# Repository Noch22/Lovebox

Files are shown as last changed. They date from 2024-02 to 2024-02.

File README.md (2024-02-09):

# Lovebox DIY :love_letter:

Envie d'envoyer de l'amour à ton partenaire, où simplement quelqu'un que tu aime ? Tu as envie de créer ? Ce projet est fait pour toi !

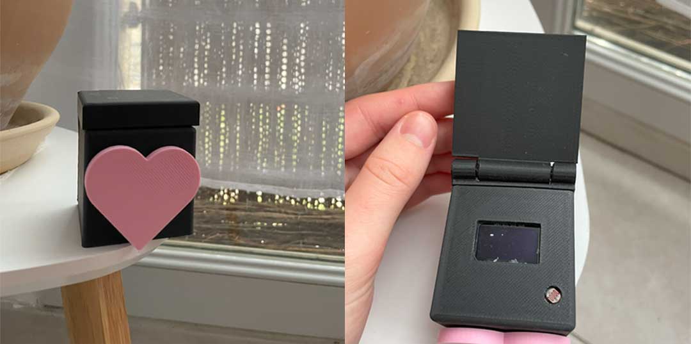
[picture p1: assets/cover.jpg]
Photo de la lovebox

## :shopping_cart: Liste des courses 
 - Wemos D1 Mini
   - [Wemos D1 Mini (cheap, cramé au bout de quelques semaine)](https://fr.aliexpress.com/item/1005006018009983.html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)
   - [Wemos D1 Mini (meilleure qualitée)](https://www.amazon.fr/AZDelivery-D1-Mini-d%C3%A9veloppement-compatible/dp/B01N9RXGHY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)
 - [Servo Moteurs](https://fr.aliexpress.com/item/1005005247828609.html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)
 - [Photorésistance](https://fr.aliexpress.com/item/1005002388823502.html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)
 - [Écran OLED](https://fr.aliexpress.com/item/32957309383.html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)
 - [Résistances 10KΩ](https://fr.aliexpress.com/item/1005005798073776.html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)

## :label: Les étapes de création

1. [**Étape 1**](#globe_with_meridians-étape-1--créer-la-base-de-données-mongodb-et-lapi) : Créer la base de données MongoDB et l'API pour envoyer des messages et les récupérer. 
Je conseille [ce tuto](https://youtu.be/FkD_tf8vkfg?si=MpVTI8Q7_iVIJIDb) en anglais qui explique très bien comment réaliser cette étape : 

   - Créer une base de données dans le cloud MongoDB.
   - Créer une API pour pouvoir interroger cette base et lui envoyer des données.

2. [**Étape 2**](#robot-étape-2--réaliser-le-bot-telegram-et-lhéberger) : Réaliser le bot Telegram et l'héberger.
    - Pour cette partie, tout le code est disponible dans le repository.
    - Créer un nouveau bot en contactant le BotFather et renseigner ses identifiants dans le fichier.
    - Héberger les fichiers du bot sur un service payant ou gratuit, possible d'utiliser [AlwaysData](https://www.alwaysdata.com/fr/) gratuitement.

3. [**Étape 3**](#electric_plug-étape-3--tester-le-code-arduino-sur-lESP8266-avec-le-montage-sur-breadboard) : Tester le code Arduino sur l'ESP8266, avec le montage sur breadboard
   - Réaliser le montage éléctronique sur breadboard (schémas disponibles).
   - Flasher le code Arduino sur l'ESP8266, ***avec le bon lien vers votre API MongoDB***
   - Tester d'envoyer un message pour voir si il s'affiche !

4. [**Étape 4**](#printer-étape-4--impression-3D) : Imprimer la boite et le coeur en 3D !
   - Pour cette étape, tous les fichiers sont disponibles dans le dossier 3DPRINT, utiliser votre slicer préféré pour slicer les fichiers pour la bonne imprimante ! Il est également possible de les modifier si il ne conviennent pas, ___attention surtout au trou à l'arrière pour brancher le cable de l'ESP8266, il est un peu petit.___

5. [**Étape 5**](#scissors-étape-5--assembler-le-tout) : Assembler le tout !
    - Et voici le moment de souder tous les composants entre eux, de bien isoler les soudures afin de tout entrer dans le boitier final ! 
    - Penser également à bien fixer le coeur sur le servomoteur, j'ai personnellement utilsé de la pate à fixe afin de pouvoir le retirer si jamais le servo venait à ne plus fonctionner.

## :globe_with_meridians: Étape 1 : Créer la base de données MongoDB et l'API

Pour ça, je vous conseille de suivre [le tuto de MongoDB ](https://youtu.be/FkD_tf8vkfg?si=MpVTI8Q7_iVIJIDb). 

Mettez en place 2 HTTPS ENDPOINTS, un pour récupérer les messages et l'autre pour en envoyer. 

**Pour récupérer uniquement le dernier message, utilisez le code suivant dans la partie fonction, en remplaçant par le bon nom de base évidemment :**

```javascript
exports = function({ query, headers, body}, response) {

    const doc = context.services
    .get("mongodb-atlas")
    .db("Lovebox")
    .collection("messages")
    .find({})

    //Récupère uniquement le dernier message entré
    .sort({$natural: -1}) 
    .limit(1)

    .toArray();
    return doc;

};
```

## :robot: Étape 2 : Réaliser le bot Telegram et l'héberger

1. Créer un Bot télégram en contactant @BotFather
    - Envoyer /newbot afin de commencer la création du bot.
    - Donner le nom du bot voulu
    - Donner le username, il doit être en minuscule et finir par bot

    BotFather vous renvois alors toutes les infos nécessaires afin de communiquer avec notre bot, ce qui nous intéresse ici est le **TOKEN**. Il est sous la forme `987654:AABBCClljjgggffgkk-abc`...

    BotFather vous communique également le lien de la conversation pour communiquer avec votre bot, cliquable sur le lien `t.me/NomDuBot`

2. Initier le bot Telegram
    - Télécharger le fichier telegram_bot.js ainsi que le package.json
        - Installer les packages avec un npm init dans le dossier ou se trouve le fichier telegram_bot.js et le package.json (avoir node js d'installé sur votre machine ainsi que npm)
    - Modifier le fichier telegram_bot.js avec le token donné par BotFather (line 8)
        ```javascript
        const bot = new Bot("VOTRE TOKEN ICI");
        ```
    - Modifier le fichier avec le lien vers votre API crée précédemment, le lien renseigné doit-être celui pour ajouter une entrée dans la base de données. (line 31)
        ```javascript
        fetch("https://le_lien_de_votre_API_ICI", requestOptions)
        ```
    - Entrez votre CHATID ligne 47 et 50 afin de restreindre qui peux envoyer un message ou non via le bot.
        ```js
        if(chatId != 'votre chat id ici, pour que vous soyez le seul à pouvoir envoyer un message'){

        ctx.reply("Tu ne peux pas utiliser ce bot !");
        console.log("refuse " + chatId);

        }else if(chatId == 'votre chat id ici, pour que vous soyez le seul à pouvoir envoyer un message') {

        await ctx.conversation.enter("newmess");
        console.log("accepted" + chatId);
        }
        });
        ```

    - Communiquer avec votre bot télégram et voir si il réponds, si il vous réponds, vérifier dans votre base de données si le message est bien rentré. Si c'est le cas, bravo ! Vous avez fait une bonne partie du travail.

3. Hébérger le bot afin d'y avoir accès 24H/24 et 7J/7.

    Pour cette étape, vous êtes libres d'utiliser le service que vous voulez, si vous disposez déjà d'un hébergeur proposant du nodeJS, c'est possible de passer par celui-ci. Sinon, je vous propose d'utiliser [AlwaysData](https://www.alwaysdata.com/), qui propose une offre gratuite à vie, avec 100mo de stockage. Ce qui est bien assez suffisant pour héberger notre petit fichier et ses dépendances.

Pour ça, rendez-vous sur le [site](https://www.alwaysdata.com/). Créez vous un compte.

1. Déposez vos fichiers grâce au FTP dans le dossier www.

1. Connectez-vous au SSH, lancez un npm init dans le bon dossier
1. Lancez ensuite un npm start et le bot devrais se lancer
1. Rendez-vous dans l'onglet Tâches planifiées sur AlwaysData et ajoutez une tâche tous les jours à minuit pour redémarrer le bot automatiquement. La commande est npm start

___Bravo, votre bot est hébergé !___ passons dès à présent au nerf de la guerre, l'arduino et l'éléctronique.
## :electric_plug: Étape 3 : Tester le code Arduino sur l'ESP8266, avec le montage sur breadboard

1. Réaliser le montage sur breadboard (schéma de cablage)
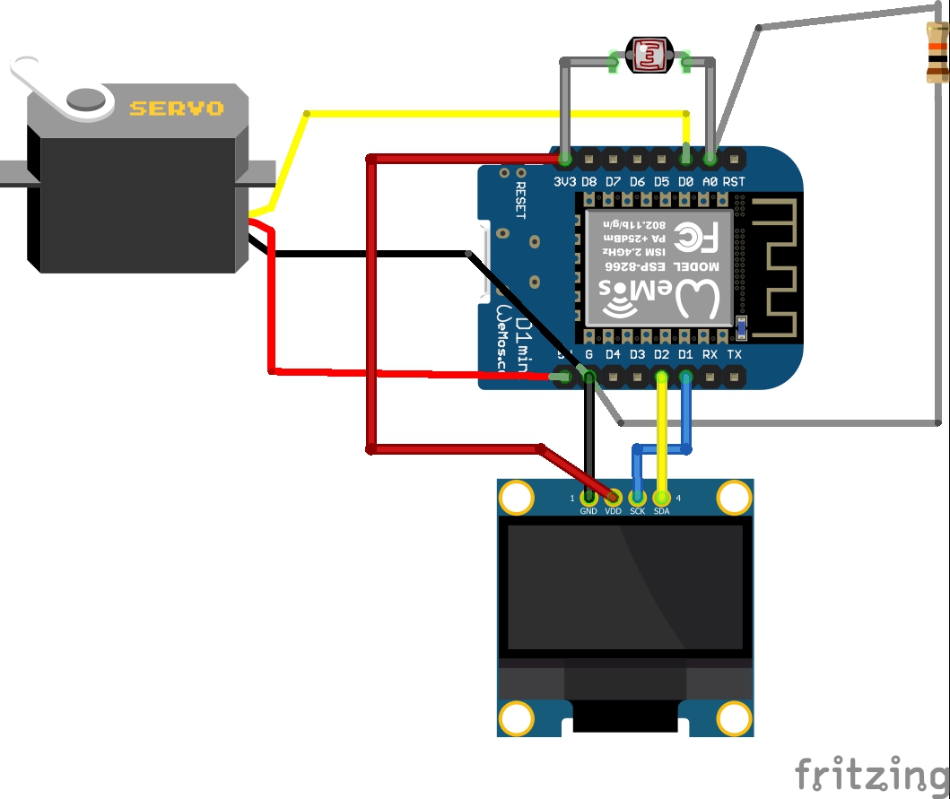
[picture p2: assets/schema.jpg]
Schéma de cablage


2. Lorsque le montage est réalisé, télécharger l'IDE Arduino (si pas encore fait).

3. Télécharger le code disponible dans le dossier ARDUINO et l'ouvrir.
    - Installer toutes les librairies inclues.

4. Personnaliser le code
 - Modifier le code ligne 129 avec votre lien, créé précédemment pour récupérer le dernier message de la base de données. 

    ```arduino
     ligne .129   // Adresse URL de la requête
    String url = "https://le_lien_pour_recupérer_le_dernier_message";
    ```

 - Changer le nom ligne 46 avec le nom de la personne à qui l'objet est déstiné.

 ```arduino
   display.ecrire("LoveBox de prénom", 0, 1);
 ```

 5. Téléverser le code sur votre Wemos D1 Mini et tester le bon fonctionnement de celui-ci.

 6. Connectez le D1 MINI au wifi depuis votre smartphone.
    - Lors de son initialisation, il cherche à se connecter à un réseau pré enregistré. Si il n'y arrive pas, il se met alors en mode émission. 
        - Se connecter au réseau "Lovebox", une page devrais s'ouvrir seule, si ce n'est pas le cas se rendre sur **192.168.4.1**.
        - Cliquer sur "Configure Wifi" et séléctionner votre réseau, y renseigner le mot de passe eet cliquer sur "Save" en bas.
    
    **Cette opération est à effectuer à chaque fois que vous déplacez la Lovebox de lieu, si le réseau wifi n'est pas le même évidemment. Si vous la débranchez et rebranchez, elle se reconnectera automatiquement.**
 \
*Tout fonctionne ? Bravo ! votre LoveBox est bientôt terminée ! Il vous reste plus qu'à imprimer le boitier !*
## :printer: Étape 4 : Impression 3D

Tous les fichiers sont disponible dans le dossier 3DPRINT, téléchargez les et modifiez les à votre guise. 

**:warning: Attention à bien imprimer le couvercle à la verticale** afin que la charnière à l'intérieur puisse fonctionner correctement.

**:warning:Attention également à la taille du trou pour passer le câble à l'arrière de la box,** celui-ci peut-être trop petit suivant l'épaisseur de votre cable.

Tout s'est bien passé ? Bravo vous avez votre boitier !

## :scissors: Étape 5 : Assembler le tout

Il est l'heure de sortir fils, fer à souder et étain !

Reliez tous vos composants à votre D1 mini, en prenant bien soin d'isoler les câbles avec de la gaine thermorectractable ou du scotch isolant ! 

Prenez bien en compte la petite taille de la boîte lorsque vous choissisez la taille de chaque file, **c'est petit !**

Une fois tout soudé, insérez le circuit dans la petite boite, et faite de votre mieux pour fixer chaque élément. J'ai personnellement utilisé de la colle à chaud pour fixer l'écran sur le haut ainsi que le cerveau moteur, l'arduino et la photorésistance. 

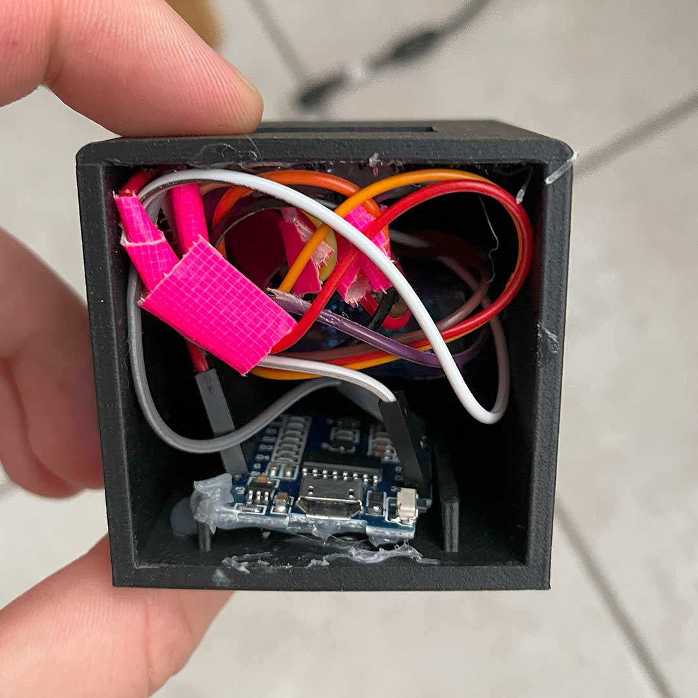
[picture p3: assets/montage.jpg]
Photo du montage final


Une fois assemblée, votre boîte est prête ! Offrez de l'amour :heart_eyes_cat: à votre entourage !
## :heart: Remerciements 

Merci à [julisa99](https://github.com/julisa99/Lovebox), un repository qui m'as beaucoup aidé lors de la création de ma propre Lovebox. Je m'en suis beaucoup inspiré et adapté le code avec le bot telegram ainsi que la base de données.

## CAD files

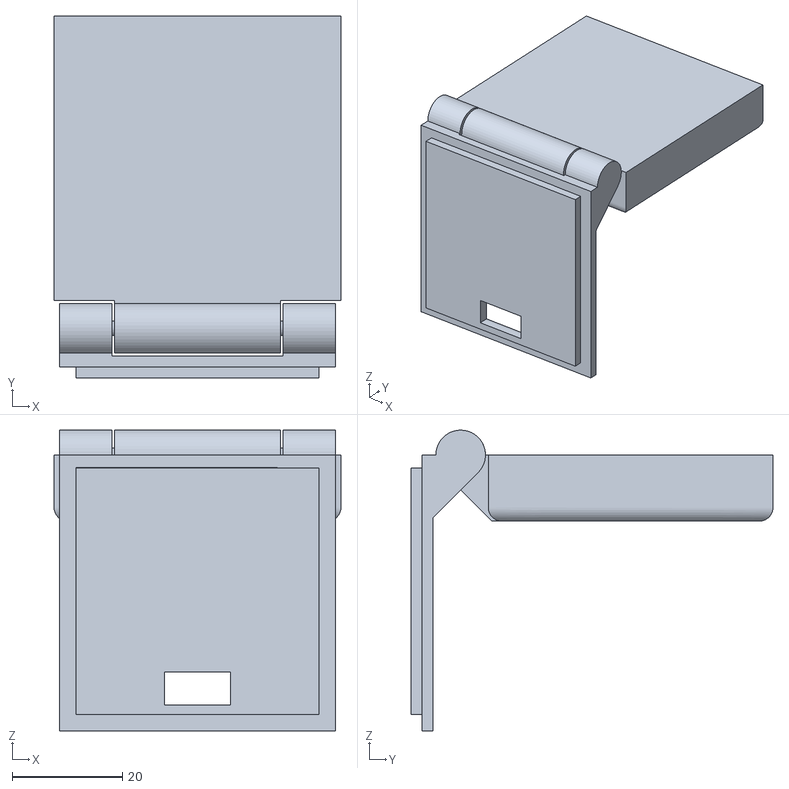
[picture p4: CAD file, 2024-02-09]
3DPRINT/ASSEMBLAGE.stl
52.0 x 65.6 x 54.5

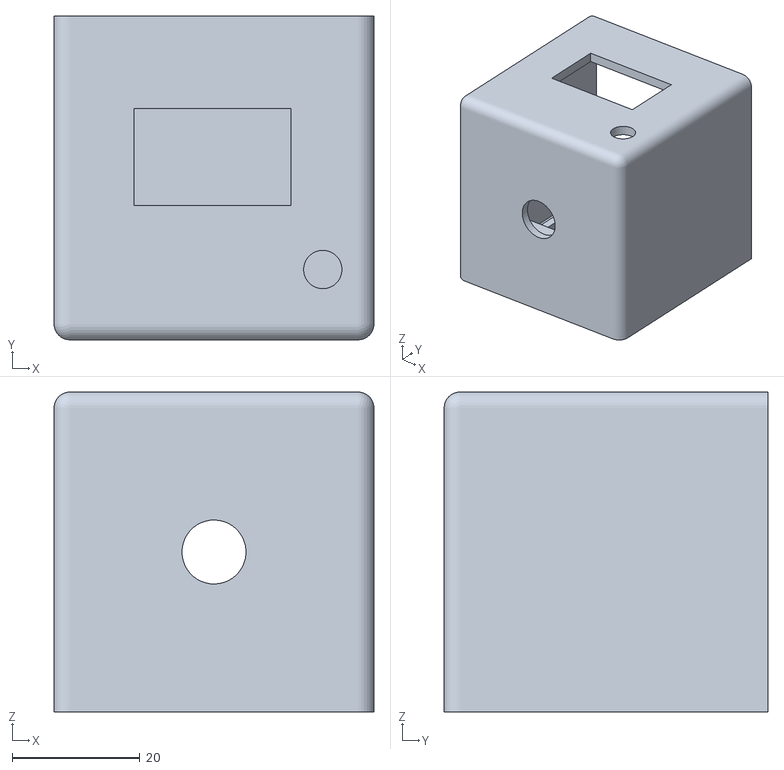
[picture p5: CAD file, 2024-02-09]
3DPRINT/boite.stl
50.0 x 50.6 x 50.0

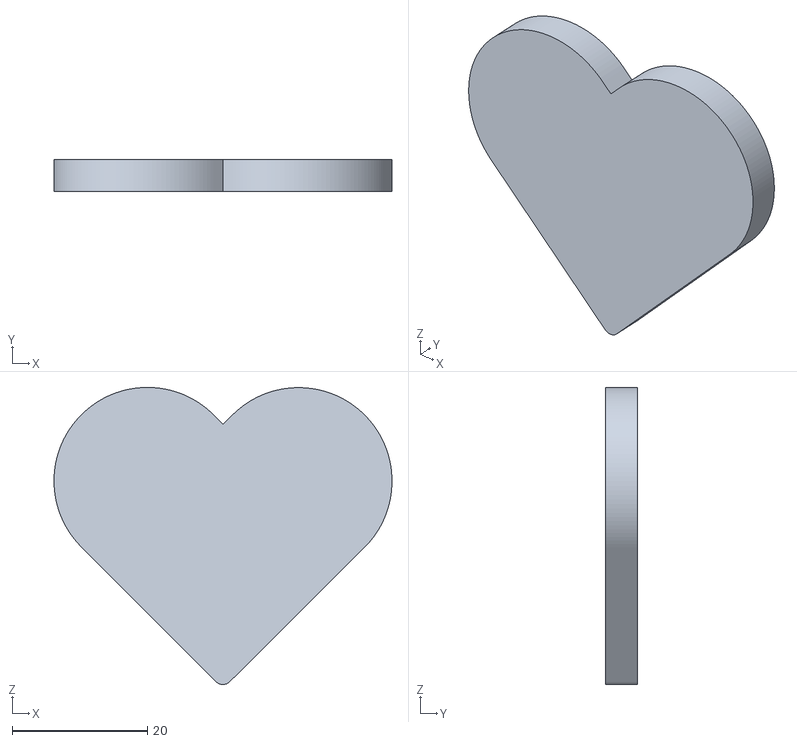
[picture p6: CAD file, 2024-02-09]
3DPRINT/coeur.stl
49.9 x 4.80 x 43.9

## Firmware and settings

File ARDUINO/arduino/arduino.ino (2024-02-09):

#include <WiFiManager.h>
#include <Servo.h>
#include <Wire.h>
#include <ESP8266HTTPClient.h>
#include <BearSSLHelpers.h>
#include <ArduinoJson.h>
#include "Ecran.h"
Ecran display;
#define motorPin 16
int photo = A0;
Servo servo;
int pos = 90;
int position = 0;
int increment = -1;
String lastid;
String lastmsg;
const char* text;

unsigned long previousFiveMinutes = 0;  // Stocke le temps du dernier déclenchement de la fonction toutes les 5 minutes
const long fiveMinutesInterval = 300000;  // Intervalle de 5 minutes en millisecondes (300,000 ms)
// const long fiveMinutesInterval = 5000;  //intervale de 5 secondes pour le debug

void setup() {
  WiFi.mode(WIFI_STA);  // explicitly set mode, esp defaults to STA+AP
  WiFiManager wm;
  bool res;
  // *********************************
  // **                             **
  // **     Port servo moteur       **
  // **                             **
  // *********************************

  servo.attach(motorPin);

  // *********************************
  // **                             **
  // **     Clear,test screen       **
  // **                             **
  // *********************************

  const char* points[] = { ".", "..", "...", "...." };

  display.begin();
  display.effacer();
  // display.setCursor(0, 0);
  display.ecrire("LoveBox de prénom", 0, 1);
  display.refresh();
  for (const char* element : points) {
    // display.setCursor(0, 20);
    display.ecrire(element, 1, 1);
    display.refresh();
    delay(500);
  }
  delay(1000);
  display.effacer();
  display.refresh();
  display.ecrire("Connexion au wifi :", 0, 1);
  display.refresh();
  delay(5000);
  display.effacer();
  display.refresh();
  // *********************************
  // **                             **
  // **     Connexion au wifi       **
  // **                             **
  // *********************************

  Serial.begin(115200);
  // Se connecter au réseau Wi-Fi
  res = wm.autoConnect("Lovebox");  // password protected ap
  if (WiFi.status() != WL_CONNECTED) {
    while (WiFi.status() != WL_CONNECTED){
    Serial.println("Failed to connect");
    display.ecrire("Mauvais paramétrage du Wifi", 0, 1);
    display.refresh();
    }
  } else {
    //if you get here you have connected to the WiFi
    display.effacer();
    display.ecrire("Connecté au wifi !", 0, 1);
    display.refresh();
    Serial.println("Connecté au WiFi!");
    delay(2000);
  }

  pinMode(photo, INPUT);
  makeHttpRequest();
}

void loop() {
  unsigned long currentMillis = millis();
  display.refresh();

  int lecture = analogRead(photo);
  Serial.print("Lecture analogique : ");
  Serial.println(lecture);
  if (lecture <= 50) {
    EteindreEcran();
  } else {
    Ecran(lastmsg);
  }



  // *********************************
  // **                             **
  // **     Fonction toutes         **
  // **     les 5 minutes           **
  // *********************************

  if (currentMillis - previousFiveMinutes >= fiveMinutesInterval) {
    previousFiveMinutes = currentMillis;  // Mettre à jour le temps du dernier déclenchement
    makeHttpRequest();
  }
}


// *********************************
// **                             **
// **     Fonction qui fais       **
// **          la requete         **
// *********************************

void makeHttpRequest() {
  HTTPClient http;
  BearSSL::WiFiClientSecure client;

  // Adresse URL de la requête
  String url = "https://le_lien_pour_recupérer_le_dernier_message";

  // Commencer la connexion HTTP
  client.setInsecure();  // Désactiver la vérification du certificat SSL (pour le débogage uniquement)
  http.begin(client, url);

  // Envoyer la requête et attendre la réponse
  int httpCode = http.GET();

  // Vérifier le code de réponse
  if (httpCode > 0) {
    // La requête a réussi
    Serial.printf("[HTTP] Code de réponse: %d\n", httpCode);

    // Lire la réponse
    String payload = http.getString();
    Serial.println("Contenu de la réponse:");
    Serial.println(payload);

    StaticJsonDocument<200> doc;

    DeserializationError error = deserializeJson(doc, payload);

    if (error) {
      Serial.print(F("deserializeJson() failed: "));
      Serial.println(error.f_str());
      return;
    }

    JsonObject obj = doc[0];
    const char* message = obj["message"];  // "test"
    const char* id_msg = obj["_id"];
    // Ecran(message);
    // Serial.println("Id : ");
    // Serial.print(id_msg);
    lastmsg = message;
    check(id_msg, message);
  } else {
    // La requête a échoué
    Serial.printf("[HTTP] La requête a échoué, code d'erreur: %s\n", http.errorToString(httpCode).c_str());
  }

  // Fermer la connexion HTTP
  http.end();
}

// *********************************
// **                             **
// **     Fonction ecrire         **
// **      ecran oled             **
// *********************************

void Ecran(String textEcran) {
  display.effacer();
  display.ecrire(textEcran, 0, 2);
}

void EteindreEcran() {
  display.effacer();
}

// *********************************
// **                             **
// **     Fonction servomot       **
// **                             **
// *********************************

void spinServo() {
  servo.write(pos);
  delay(50);  // wait 50ms to turn servo

  if (pos == 0 || pos == 180) {  // 75°-105° range
    increment *= -1;
  }
  pos += increment;
}


void check(String chid_msg, String chmessage) {
  int lecture = analogRead(photo);
  if (lastid == chid_msg) {
    Serial.println("meme id");
    Serial.println("last id : ");
    Serial.println(lastid);

  } else {
    delay(1000);
    Serial.print("i : ");
    Serial.print(lastid);
    Serial.print("chid_msg : ");
    Serial.print(chid_msg);
    Serial.print("chmessage : ");
    Serial.print(chmessage);
    while (lecture <= 50) {
      spinServo();
      EteindreEcran();
      lecture = analogRead(photo);
      Serial.print("Le servo tourne !");
    }
    servo.write(90);
    EteindreEcran();
    Ecran(chmessage);
    delay(1000);
    lastid = chid_msg;
    Serial.print("i modifié: ");
    Serial.print(lastid);
  }
}
